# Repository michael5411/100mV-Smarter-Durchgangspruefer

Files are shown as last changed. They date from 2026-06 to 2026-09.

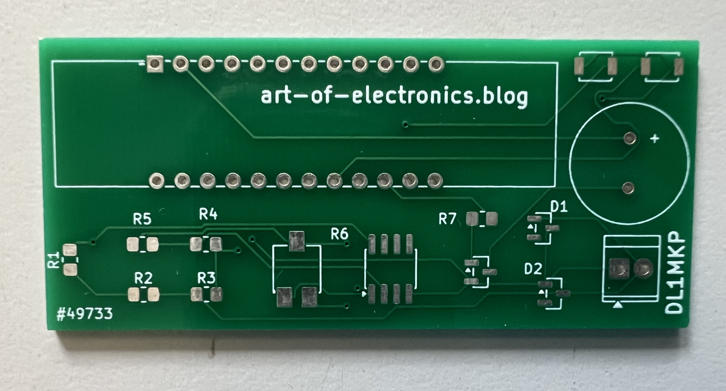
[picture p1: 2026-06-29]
SMD-Board.jpg

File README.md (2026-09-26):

SmaConTest
# 100mV-Smarter-Durchgangspruefer:
Dieses Gerät testet Durchgang und Widerstände bis 100Ω nur mit 100 mV. Dadurch können Verbindungen und viele Komponenten in eingebautem Zustand gecheckt werden, ohne dass Halbleiterübergänge die Messung verfälschen. Das Messgerät gibt verschiedene Tonfolgen für unterschiedliche Widerstandsbereiche aus. Es ist programmierbar.

Neue Versionen, neue Infos zum Projekt unter: **https://art-of-electronics.blog**

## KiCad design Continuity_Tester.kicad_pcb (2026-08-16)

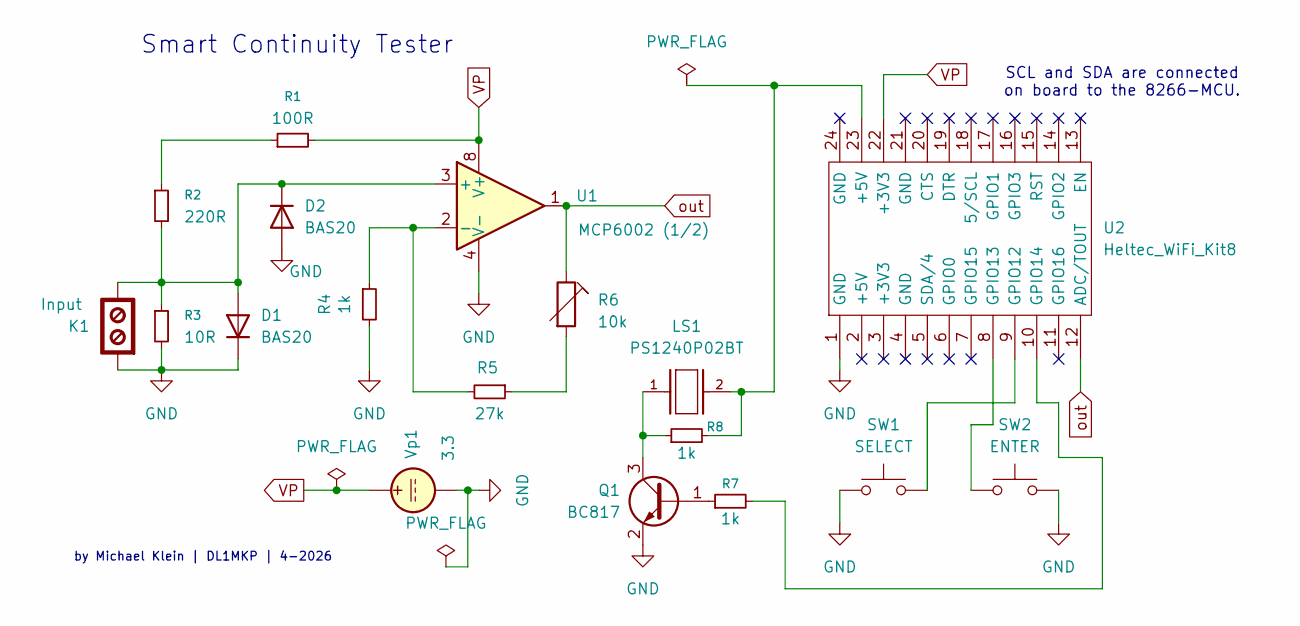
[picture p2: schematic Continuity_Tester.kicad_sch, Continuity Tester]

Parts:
D1, D2: BAS20; SOT-23
K1: Input; TerminalBlock_TE_282834-2_1x02_P2.54mm_Horizontal
LS1: PS1240P02BT; XDCR_PS1240P02BT
Q1: BC817; SOT-23
R1: 100R; R_0805_2012Metric_Pad1.20x1.40mm_HandSolder
R2: 220R; R_0805_2012Metric_Pad1.20x1.40mm_HandSolder
R3: 10R; R_0805_2012Metric_Pad1.20x1.40mm_HandSolder
R4, R7, R8: 1k; R_0805_2012Metric_Pad1.20x1.40mm_HandSolder
R5: 27k; R_0805_2012Metric_Pad1.20x1.40mm_HandSolder
R6: 10k; Potentiometer_Bourns_3314G
SW1: SELECT; SW_SPST_B3U-1000P
SW2: ENTER; SW_SPST_B3U-1000P
U1: MCP6002 (1/2); SOP-8_3.76x4.96mm_P1.27mm
U2: Heltec_WiFi_Kit8
Vp1: 3.3

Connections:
GND: D1.3 (K), D2.1 (A), K1.1, Q1.2 (E), R3.2, R4.2, SW1.1, SW2.2, U1.4 (V-), U2.1 (GND), Vp1.2
unnamed: D1.1 (A), D2.3 (K), K1.2, R2.2, R3.1, U1.3 (+)
unnamed: LS1.2, R8.2, U2.23 (+5V)
unnamed: Q1.1 (B), R7.1
unnamed: LS1.1, Q1.3 (C), R8.1
unnamed: R1.1, R2.1
unnamed: R5.1, R6.2
unnamed: R4.1, R5.2, U1.2 (-)
unnamed: SW1.2, U2.9 (GPIO12)
unnamed: SW2.1, U2.8 (GPIO13)
unnamed: R7.2, U2.10 (GPIO14)
VP: R1.2, U1.8 (V+), U2.22 (+3V3), Vp1.1
out: R6.1, U1.1, U2.12 (ADC/TOUT)

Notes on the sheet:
Smart Continuity Tester
by Michael Klein | DL1MKP | 4-2026
SCL and SDA are connected on board to the 8266-MCU.

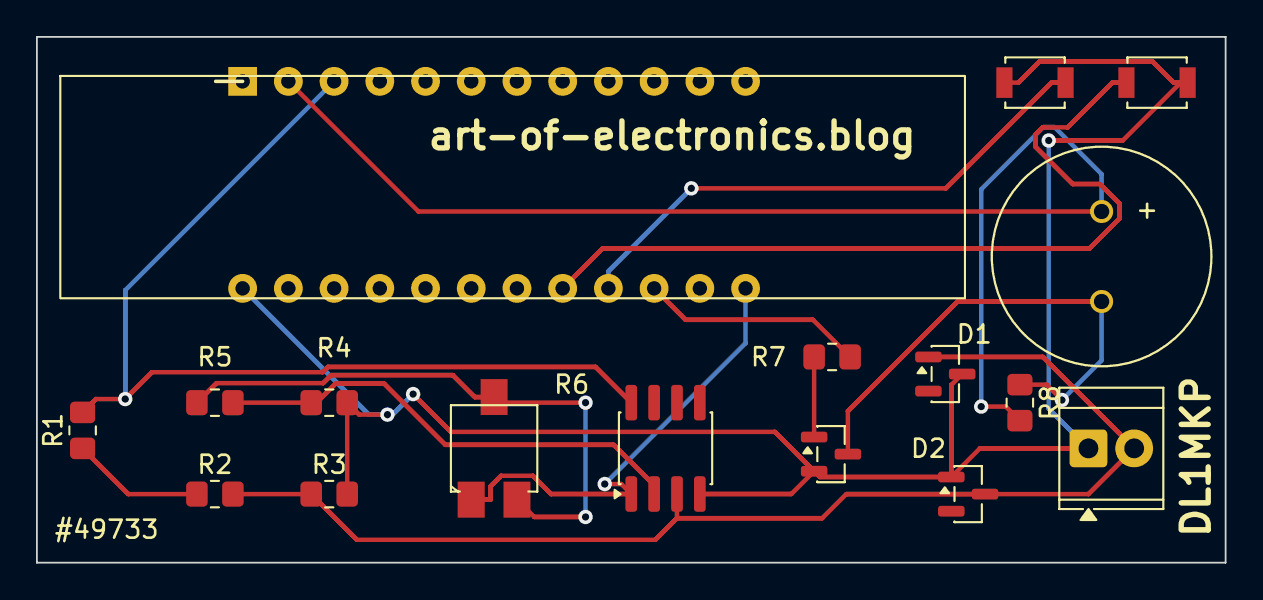
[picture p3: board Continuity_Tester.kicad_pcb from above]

Board: 2 copper layers, 66.0 x 29.2 mm, 17 parts (0 on the bottom side), 13 nets.

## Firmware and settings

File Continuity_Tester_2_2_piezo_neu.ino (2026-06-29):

#include <U8g2lib.h>
#include <Wire.h>
#include <EEPROM.h>

// ─── Hardware ────────────────────────────────────────────────────────────────
U8G2_SSD1306_128X32_UNIVISION_F_HW_I2C u8g2(U8G2_R0, 16, 5, 4);

#define PIN_SELECT  12
#define PIN_ENTER   13
#define PIN_BUZZER  14

// ─── EEPROM ───────────────────────────────────────────────────────────────────
#define EEPROM_SIZE     68
#define EEPROM_MAGIC    0xAB
#define ADDR_MAGIC      0
#define ADDR_SOUND      1
#define ADDR_LIMIT1     2
#define ADDR_LIMIT2     6
#define ADDR_LIMIT3     10
#define ADDR_CAL_FLAG   14
#define ADDR_RAWERROR   15
#define ADDR_CAL_START  17   // 15 floats × 4 Bytes = 60 Bytes

// ─── Lookup-Tabelle (Default) ─────────────────────────────────────────────────
const int LUT_SIZE = 15;
float lut_raw[LUT_SIZE] = {   3,   32,   48,   93,  134,  169,  232,  333,  412,  498,  592,  659,  739,  817,  890 };
float lut_rx[LUT_SIZE]  = { 0.0,  0.3,  0.5,  1.0,  1.5,  2.0,  3.0,  5.0,  7.0, 10.0, 15.0, 20.0, 30.0, 50.0, 100.0 };

// Default-Werte für Reset
const float LUT_RAW_DEFAULT[LUT_SIZE] = {   3,   32,   48,   93,  134,  169,  232,  333,  412,  498,  592,  659,  739,  817,  890 };
const int   RAWERROR_DEFAULT = 42;

const int   QUICK_IDX[]  = { 0, 3, 9, 12, 14 };
const float QUICK_RX[]   = { 0.0, 1.0, 10.0, 30.0, 100.0 };
const int   QUICK_SIZE   = 5;

// ─── Globale Variablen ────────────────────────────────────────────────────────
bool  soundOn  = true;
float limit1   = 1.0;
float limit2   = 10.0;
float limit3   = 50.0;
int   rawerror = RAWERROR_DEFAULT;

char  ausgabe[24]        = "";
float cal_buffer[LUT_SIZE];   // Puffer während Kalibrierung

// ─── Töne (passiver Piezo-Schallwandler PS1240P02BT) ─────────────────────────
// Der PS1240P02BT ist ein PASSIVER Wandler — er braucht ein Wechselsignal (tone()).
// Seine Resonanzfrequenz liegt bei ca. 4 kHz; wir nutzen eine feste Frequenz
// und unterscheiden die Limit-Stufen durch Pulsmuster (An-/Aus-Zeiten).
//
// Limit 1 (≤ limit1): Dauerton 4000 Hz         → Durchgang / sehr niedrig
// Limit 2 (≤ limit2): Kurze Pulse  100ms/100ms → mittlerer Widerstand
// Limit 3 (≤ limit3): Mittlere Pulse 100ms/300ms
// > Limit 3:          Langsame Pulse  100ms/700ms

#define BUZZER_FREQ  4000   // nahe Resonanzfrequenz des PS1240P02BT

void beep(int dauer_ms) {
  tone(PIN_BUZZER, BUZZER_FREQ, dauer_ms);
  delay(dauer_ms);
  noTone(PIN_BUZZER);
}

void beepUI()  { beep(100); }
void beepUI2() { beep(100); delay(100); beep(100); }

// ─── EEPROM ───────────────────────────────────────────────────────────────────
void eepromLoad() {
  EEPROM.begin(EEPROM_SIZE);
  if (EEPROM.read(ADDR_MAGIC) != EEPROM_MAGIC) return;
  soundOn = EEPROM.read(ADDR_SOUND);
  EEPROM.get(ADDR_LIMIT1,   limit1);
  EEPROM.get(ADDR_LIMIT2,   limit2);
  EEPROM.get(ADDR_LIMIT3,   limit3);
  EEPROM.get(ADDR_RAWERROR, rawerror);
  if (EEPROM.read(ADDR_CAL_FLAG) == 1) {
    for (int i = 0; i < LUT_SIZE; i++) {
      EEPROM.get(ADDR_CAL_START + i * 4, lut_raw[i]);
    }
  }
}

void eepromSave() {
  EEPROM.write(ADDR_MAGIC, EEPROM_MAGIC);
  EEPROM.write(ADDR_SOUND, soundOn ? 1 : 0);
  EEPROM.put(ADDR_LIMIT1,   limit1);
  EEPROM.put(ADDR_LIMIT2,   limit2);
  EEPROM.put(ADDR_LIMIT3,   limit3);
  EEPROM.put(ADDR_RAWERROR, rawerror);
  EEPROM.commit();
}

// Wird nur aufgerufen wenn Kalibrierung vollständig abgeschlossen
void eepromSaveCal() {
  // Erst jetzt cal_buffer → lut_raw übernehmen
  for (int i = 0; i < LUT_SIZE; i++) {
    lut_raw[i] = cal_buffer[i];
  }
  EEPROM.write(ADDR_MAGIC,    EEPROM_MAGIC);
  EEPROM.write(ADDR_CAL_FLAG, 1);
  EEPROM.put(ADDR_RAWERROR, rawerror);
  for (int i = 0; i < LUT_SIZE; i++) {
    EEPROM.put(ADDR_CAL_START + i * 4, lut_raw[i]);
  }
  EEPROM.commit();
}

void eepromReset() {
  // Alle Werte auf Default zurücksetzen
  soundOn  = true;
  limit1   = 1.0;
  limit2   = 10.0;
  limit3   = 50.0;
  rawerror = RAWERROR_DEFAULT;
  for (int i = 0; i < LUT_SIZE; i++) {
    lut_raw[i] = LUT_RAW_DEFAULT[i];
  }
  EEPROM.write(ADDR_MAGIC,    EEPROM_MAGIC);
  EEPROM.write(ADDR_SOUND,    1);
  EEPROM.write(ADDR_CAL_FLAG, 0);
  EEPROM.put(ADDR_LIMIT1,   limit1);
  EEPROM.put(ADDR_LIMIT2,   limit2);
  EEPROM.put(ADDR_LIMIT3,   limit3);
  EEPROM.put(ADDR_RAWERROR, rawerror);
  EEPROM.commit();
}

// ─── Display ──────────────────────────────────────────────────────────────────
void dispText(const char* z1, const char* z2 = nullptr) {
  u8g2.clearBuffer();
  u8g2.setFont(u8g2_font_ncenB08_tr);
  if (z1) u8g2.drawStr(0, 12, z1);
  if (z2) u8g2.drawStr(0, 28, z2);
  u8g2.sendBuffer();
}

void dispGroß(const char* text, int x_offset = 0) {
  u8g2.clearBuffer();
  u8g2.setFont(u8g2_font_logisoso24_tf);
  int breite = u8g2.getUTF8Width(text);
  int x = (128 - breite) / 2 + x_offset;
  u8g2.drawUTF8(x, 28, text);
  u8g2.sendBuffer();
}

void dispMenu(const char** items, int anzahl, int sel) {
  char z1[24], z2[24];
  int idx2 = (sel + 1) % anzahl;
  snprintf(z1, sizeof(z1), "> %s", items[sel]);
  snprintf(z2, sizeof(z2), "  %s", items[idx2]);
  dispText(z1, z2);
}

// ─── Tasten ───────────────────────────────────────────────────────────────────
bool selectPressed() { return digitalRead(PIN_SELECT) == LOW; }
bool enterPressed()  { return digitalRead(PIN_ENTER)  == LOW; }

void waitRelease() {
  while (selectPressed() || enterPressed()) delay(10);
  delay(50);
}

bool abbruchGedrueckt() {
  if (selectPressed() && enterPressed()) {
    int t = 0;
    while (selectPressed() && enterPressed()) {
      delay(100); t += 100;
      if (t >= 1000) {
        beepUI();
        dispText("Abbruch", "");
        delay(1000);
        waitRelease();
        return true;
      }
    }
  }
  return false;
}

int enterHaltezeit(int schwelle_ms = 0, const char* anzeigeText = nullptr) {
  int t = 0;
  bool signalGegeben = false;
  while (enterPressed()) {
    delay(100); t += 100;
    if (!signalGegeben && schwelle_ms > 0 && t >= schwelle_ms) {
      beepUI();
      if (anzeigeText) dispText(anzeigeText, "");
      signalGegeben = true;
    }
  }
  return t;
}

// ─── Lookup ───────────────────────────────────────────────────────────────────
float lookup_rx(int raw) {
  if (raw <= lut_raw[0])            return 0.0;
  if (raw >= lut_raw[LUT_SIZE - 1]) return 9999.0;
  for (int i = 1; i < LUT_SIZE; i++) {
    if (raw <= lut_raw[i]) {
      float divisor = lut_raw[i] - lut_raw[i-1];
      if (divisor == 0) return lut_rx[i-1];  // Schutz vor nan
      float t = (raw - lut_raw[i-1]) / divisor;
      return lut_rx[i-1] + t * (lut_rx[i] - lut_rx[i-1]);
    }
  }
  return 9999.0;
}

// ─── Kalibrierung ─────────────────────────────────────────────────────────────
bool calEinzelMessung(int idx, float r_soll) {
  char z1[24];
  if (r_soll == 0.0)
    snprintf(z1, sizeof(z1), "Kurzschluss anlegen");
  else
    snprintf(z1, sizeof(z1), "%.1f Ohm anlegen", r_soll);
  dispText(z1, "ENTER druecken");

  while (true) {
    if (abbruchGedrueckt()) return false;
    if (enterPressed()) {
      waitRelease();
      int raw = analogRead(A0) - rawerror;
      if (raw < 0) raw = 0;
      cal_buffer[idx] = raw;    // in Puffer, nicht direkt in lut_raw
      char z2[24];
      snprintf(z2, sizeof(z2), "RAW=%d OK", (int)cal_buffer[idx]);
      dispText(z1, z2);
      beepUI();
      delay(1000);
      return true;
    }
    delay(20);
  }
}

void interpoliereQuick() {
  for (int seg = 0; seg < QUICK_SIZE - 1; seg++) {
    int i0 = QUICK_IDX[seg];
    int i1 = QUICK_IDX[seg + 1];
    float raw0 = cal_buffer[i0];
    float raw1 = cal_buffer[i1];
    for (int i = i0 + 1; i < i1; i++) {
      float t = (lut_rx[i] - lut_rx[i0]) / (lut_rx[i1] - lut_rx[i0]);
      cal_buffer[i] = raw0 + t * (raw1 - raw0);
    }
  }
}

bool menuCalQuick() {
  dispText("Schnellkal. 5 Pkte", "ENTER zum Start");
  waitRelease();
  while (!enterPressed()) {
    if (abbruchGedrueckt()) return false;
    delay(20);
  }
  waitRelease();

  dispText("Klemmen kurzschl.", "dann ENTER");
  while (true) {
    if (abbruchGedrueckt()) return false;
    if (enterPressed()) {
      rawerror = analogRead(A0);
      waitRelease();
      beepUI();
      break;
    }
    delay(20);
  }

  for (int i = 0; i < QUICK_SIZE; i++) {
    if (!calEinzelMessung(QUICK_IDX[i], QUICK_RX[i])) return false;
  }
  interpoliereQuick();
  eepromSaveCal();
  dispText("Kalibrierung OK", "Werte gespeichert");
  beepUI2();
  delay(2000);
  return true;
}

bool menuCalFull() {
  dispText("Vollkal. 15 Pkte", "ENTER zum Start");
  waitRelease();
  while (!enterPressed()) {
    if (abbruchGedrueckt()) return false;
    delay(20);
  }
  waitRelease();

  dispText("Klemmen kurzschl.", "dann ENTER");
  while (true) {
    if (abbruchGedrueckt()) return false;
    if (enterPressed()) {
      rawerror = analogRead(A0);
      waitRelease();
      beepUI();
      break;
    }
    delay(20);
  }

  for (int i = 0; i < LUT_SIZE; i++) {
    if (!calEinzelMessung(i, lut_rx[i])) return false;
  }
  eepromSaveCal();
  dispText("Kalibrierung OK", "Werte gespeichert");
  beepUI2();
  delay(2000);
  return true;
}

void menuCalibration() {
  const char* items[] = { "Quick (5 Punkte)", "Full  (15 Punkte)" };
  const int anzahl = 2;
  int sel = 0;

  while (true) {
    dispMenu(items, anzahl, sel);
    if (selectPressed()) { sel = (sel + 1) % anzahl; waitRelease(); delay(150); }
    if (enterPressed()) {
      waitRelease();
      dispText("ENTER 3s halten", "zum Starten");
      // Warten bis ENTER neu gedrückt wird
      while (!enterPressed()) delay(20);
      int t = enterHaltezeit(3000, "Calibration...");
      if (t >= 3000) {
        waitRelease();
        if (sel == 0) menuCalQuick();
        else          menuCalFull();
        return;
      } else {
        waitRelease();
        dispText("Abgebrochen", "");
        delay(1000);
      }
    }
    delay(50);
  }
}

// ─── Reset Default ────────────────────────────────────────────────────────────
void menuReset() {
  dispText("ENTER 3s halten", "fuer Reset");
  // Warten bis ENTER neu gedrückt wird
  while (!enterPressed()) delay(20);
  int t = enterHaltezeit(3000, "Reset...");
  if (t >= 3000) {
    waitRelease();
    eepromReset();
    dispText("Reset OK", "Default-Werte aktiv");
    beepUI2();
    delay(2000);
  } else {
    waitRelease();
    dispText("Abgebrochen", "");
    delay(1000);
  }
}

// ─── Limits ───────────────────────────────────────────────────────────────────
void setEinLimit(int nr, float* limit) {
  char z1[24];
  snprintf(z1, sizeof(z1), "Limit %d anlegen", nr);
  dispText(z1, "dann ENTER");
  waitRelease();
  while (!enterPressed()) delay(20);
  int raw = analogRead(A0) - rawerror;
  if (raw < 0) raw = 0;
  float r = lookup_rx(raw);
  *limit = r;
  char z2[24];
  snprintf(z2, sizeof(z2), "= %.1f Ohm", r);
  dispText(z1, z2);
  beepUI();
  waitRelease();
  delay(1500);
}

void menuLimits() {
  const char* items[] = { "Limit 1", "Limit 2", "Limit 3" };
  const int anzahl = 3;
  int sel = 0;
  while (true) {
    dispMenu(items, anzahl, sel);
    if (selectPressed()) { sel = (sel + 1) % anzahl; waitRelease(); delay(150); }
    if (enterPressed()) {
      waitRelease();
      if      (sel == 0) setEinLimit(1, &limit1);
      else if (sel == 1) setEinLimit(2, &limit2);
      else               setEinLimit(3, &limit3);
      eepromSave();
      return;
    }
    delay(50);
  }
}

// ─── Sound ────────────────────────────────────────────────────────────────────
void menuSound() {
  const char* items[] = { "ON", "OFF" };
  const int anzahl = 2;
  int sel = soundOn ? 0 : 1;
  while (true) {
    dispMenu(items, anzahl, sel);
    if (selectPressed()) { sel = (sel + 1) % anzahl; waitRelease(); }
    if (enterPressed()) {
      soundOn = (sel == 0);
      eepromSave();
      beepUI();
      waitRelease();
      return;
    }
    delay(50);
  }
}

// ─── Hauptmenü ────────────────────────────────────────────────────────────────
void hauptmenu() {
  const char* items[] = { "Sound ON/OFF", "Set Limits", "Calibration", "Reset Default" };
  const int anzahl = 4;
  int sel = 0;
  while (true) {
    dispMenu(items, anzahl, sel);
    if (selectPressed()) { sel = (sel + 1) % anzahl; waitRelease(); delay(150); }
    if (enterPressed()) {
      waitRelease();
      if      (sel == 0) menuSound();
      else if (sel == 1) menuLimits();
      else if (sel == 2) menuCalibration();
      else               menuReset();
      return;
    }
    delay(50);
  }
}

// ─── Setup ────────────────────────────────────────────────────────────────────
void setup() {
  pinMode(PIN_BUZZER, OUTPUT);
  digitalWrite(PIN_BUZZER, LOW);
  pinMode(PIN_SELECT, INPUT_PULLUP);
  pinMode(PIN_ENTER,  INPUT_PULLUP);
  Serial.begin(9600);
  u8g2.begin();
  // EINMALIG — nach dem Flashen wieder entfernen!
  // EEPROM.begin(EEPROM_SIZE);
  // EEPROM.write(ADDR_MAGIC,    0x00);
  // EEPROM.write(ADDR_CAL_FLAG, 0x00);
  // EEPROM.commit();
  eepromLoad();
  // cal_buffer initiallisieren
  for (int i = 0; i < LUT_SIZE; i++) {
    cal_buffer[i] = lut_raw[i];
  }
  // Debug: lut_raw[] und rawerror ausgeben
  Serial.print("rawerror: "); Serial.println(rawerror);
  for (int i = 0; i < LUT_SIZE; i++) {
    Serial.print("lut_raw["); Serial.print(i);
    Serial.print("] = "); Serial.println(lut_raw[i]);
  }
  dispText("Continuity Tester", "art-of-electronics");
  delay(2000);
}

// ─── Hauptschleife ────────────────────────────────────────────────────────────
void loop() {
  if (enterPressed()) {
    int t = enterHaltezeit(5000, "Menue");
    if (t >= 5000) {
      waitRelease();
      hauptmenu();
      return;
    }
  }

  int adc_roh = analogRead(A0) - rawerror;
  if (adc_roh < 0) adc_roh = 0;
  float r_x = lookup_rx(adc_roh);

  Serial.print("RAW: "); Serial.print(adc_roh);
  Serial.print("  Rx: "); Serial.println(r_x, 1);

  if (r_x >= 9999.0) {
    dispGroß("Overflow");
  } else {
    char zahl[12] = "";
    if (r_x < 10.0) dtostrf(r_x, 4, 1, zahl);
    else             dtostrf(r_x, 4, 0, zahl);
    snprintf(ausgabe, sizeof(ausgabe), "%s Ohm", zahl);
    dispGroß(ausgabe, -8);
  }

  if (soundOn && r_x < 9999.0) {
    // ── Passiver Piezo PS1240P02BT: tone() + Pulsmuster je Widerstandsbereich ─
    // Limit 1 (≤ limit1): Dauerton                  → Durchgang / sehr niedrig
    // Limit 2 (≤ limit2): Kurze Pause  100ms/100ms  → mittlerer Widerstand
    // Limit 3 (≤ limit3): Mittlere Pause 100ms/300ms
    // > Limit 3:          Langsame Pause  100ms/700ms
    unsigned long start = millis();
    while (millis() - start < 3000) {
      int raw2 = analogRead(A0) - rawerror;
      if (raw2 < 0) raw2 = 0;
      float r2 = lookup_rx(raw2);
      if (r2 >= 9999.0) {
        noTone(PIN_BUZZER);
        break;
      }
      if (r2 <= limit1) {
        // Dauerton: tone() läuft durch, nur kurz neu getriggert
        tone(PIN_BUZZER, BUZZER_FREQ);
        delay(100);
      } else if (r2 <= limit2) {
        // Kurze Pulse: 100ms an / 100ms aus
        tone(PIN_BUZZER, BUZZER_FREQ);
        delay(100);
        noTone(PIN_BUZZER);
        delay(100);
      } else if (r2 <= limit3) {
        // Mittlere Pulse: 100ms an / 300ms aus
        tone(PIN_BUZZER, BUZZER_FREQ);
        delay(100);
        noTone(PIN_BUZZER);
        delay(300);
      } else {
        // Langsame Pulse: 100ms an / 700ms aus
        tone(PIN_BUZZER, BUZZER_FREQ);
        delay(100);
        noTone(PIN_BUZZER);
        delay(700);
      }
    }
    noTone(PIN_BUZZER);
  }

  delay(200);
}

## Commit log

2026-06-29 KiCad10 Schaltplan
    [Continuity_Tester.kicad_sch]
2026-06-29 Detaillierte Projektbeschreibung
    1) Projektbeschreibung
    2) Erklärung des Arduino C++ Codes
    3) Bedienungsanleitung für das Gerät
2026-06-29 Update README with device description and image
2026-06-29 Professionelles SMD-board
    Bitte email an: michael (ät) art-of-electronics.blog.
2026-09-26 Delete Smarter 100mV-Durchgangsprüfer_DE.pdf
    Alte Version
